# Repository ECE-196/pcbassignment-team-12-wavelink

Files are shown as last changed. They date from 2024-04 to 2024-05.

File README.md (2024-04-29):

Review Assignment Due Date (https://classroom.github.com/a/_vaYiJHp)
# PCBAssignment

**Use the KiCAD project in this repository to make your PCB.**

**Remember to update the changelog**

# Submission

> NOTE: This assignment has multiple deadlines!

> NOTE: This assignment has **no auto-checker** (since there are multiple deadlines), double check you have everything!

1. Image of schematic named `schematic.*` placed in root of this repository. _(By Sunday April 28th)_
1. Image of revised schematic named `schematic.*` and image of layout named `layout.*` placed in root of this repository. _(By Tuesday April 30th)_
1. Final PCB updated in KiCAD project. _(By Friday May 3rd)_
1. Gerber file output ZIP archive named `export.zip` in root of this repository. _(By Friday May 3rd)_
1. Updated changelog

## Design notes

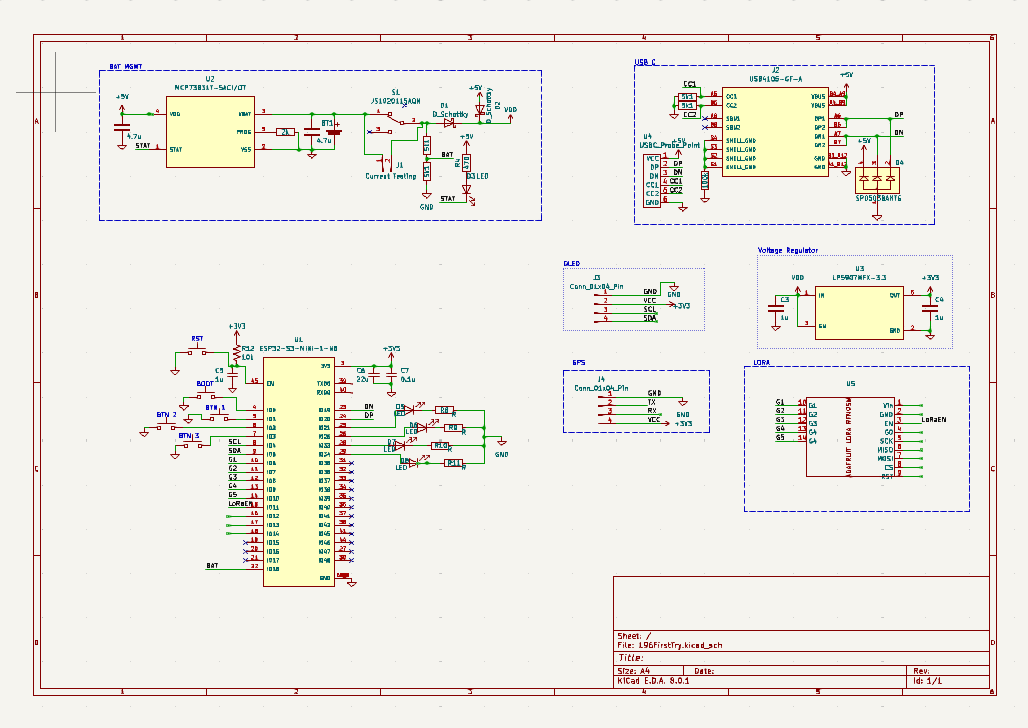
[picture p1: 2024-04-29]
schematic.png

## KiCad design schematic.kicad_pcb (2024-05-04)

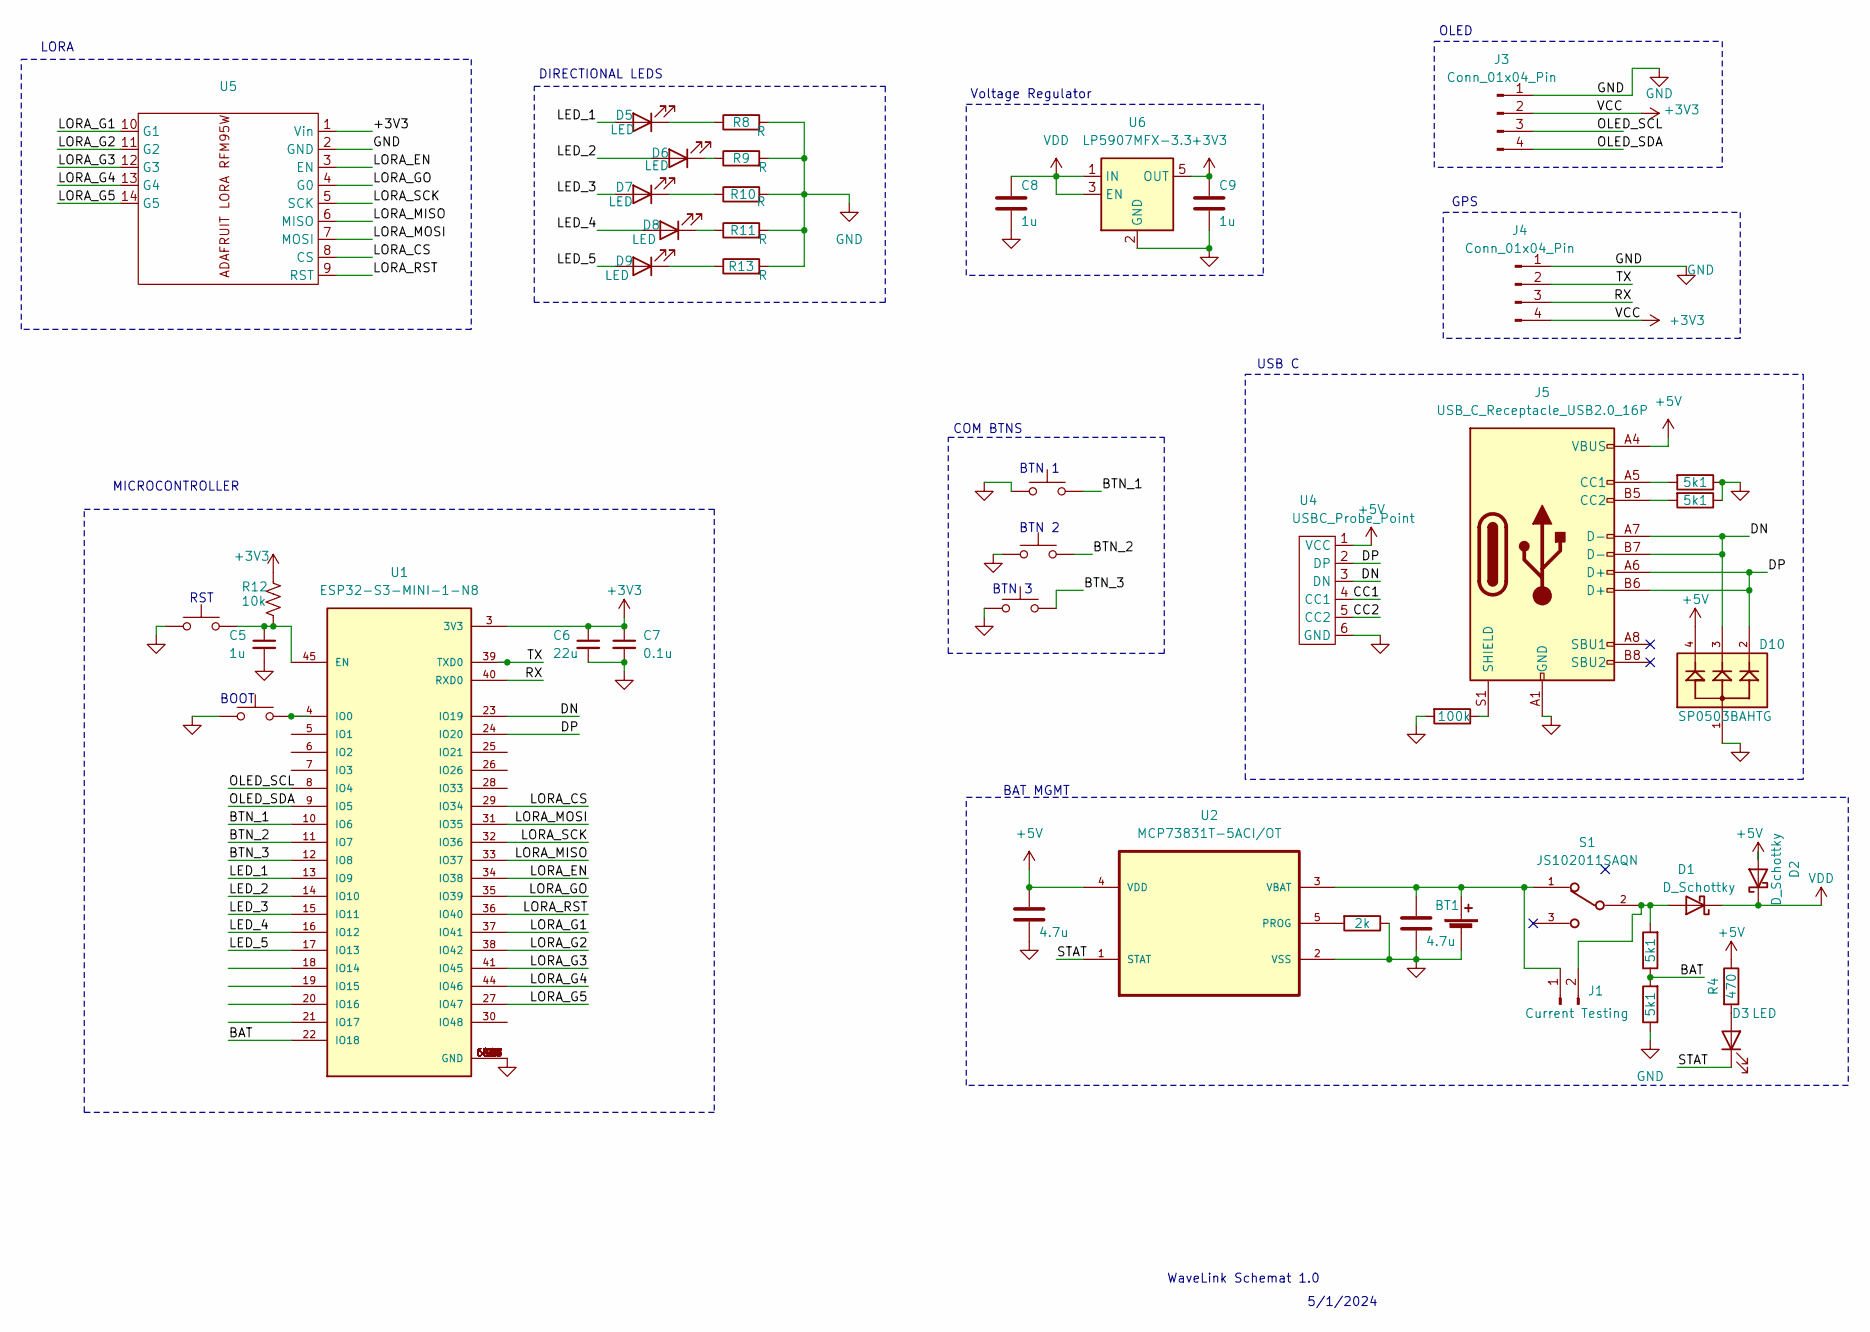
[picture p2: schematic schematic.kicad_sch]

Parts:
BT1: 3.7; PinSocket_1x02_P2.54mm_Vertical
C1, C2: 4.7u; C_0805_2012Metric
C5, C8, C9: 1u; C_0805_2012Metric
C6: 22u; C_0805_2012Metric
C7: 0.1u; C_0805_2012Metric
D1, D2: D_Schottky; D_SOD-523
D3, D5, D6, D7, D8, D9: LED; LED_0805_2012Metric
D10: SP0503BAHTG; SOT-143; PARTREV N/A
J1: Current Testing; PinHeader_1x02_P1.00mm_Vertical
J3, J4: Conn_01x04_Pin; PinHeader_1x04_P2.54mm_Vertical
J5: USB_C_Receptacle_USB2.0_16P; USB_C_Receptacle_GCT_USB4105-xx-A_16P_TopMnt_Horizontal
R1: 2k; R_0805_2012Metric
R2, R3, R5, R6: 5k1; R_0805_2012Metric
R4: 470; R_0805_2012Metric
R7: 100k; R_0805_2012Metric
R8, R9, R10, R11, R13: R; R_0805_2012Metric
R12: 10k; R_0805_2012Metric
S1: JS102011SAQN; SW_SPDT_CK_JS102011SAQN
SW1, SW3, SW4, SW5, SW6: Boot; SW_Push_1P1T_NO_Vertical_Wuerth_434133025816
U1: ESP32-S3-MINI-1-N8; XCVR_ESP32-S3-MINI-1-N8; PARTREV v0.6
U2: MCP73831T-5ACI/OT; SOT-23-5; MPN MCP73831T-5ACI/OT
U4: USBC_Probe_Point; PinHeader_1x06_P1.00mm_Vertical
U5: Lora_Adafruit
U6: LP5907MFX-3.3; SOT-23-5

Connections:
+3V3: C6.1, C7.1, C9.1, J3.2, J4.4, R12.1, U1.3 (3V3), U5.1 (Vin), U6.5 (OUT)
+5V: C1.1, D2.2 (A), D10.4, J5.A4 (VBUS), J5.A9 (VBUS), J5.B4 (VBUS), J5.B9 (VBUS), R4.1, U2.4 (VDD), U4.1 (VCC)
/BAT: R2.1, R3.2, U1.22 (IO18)
/BTN_1: SW4.2, U1.10 (IO6)
/BTN_2: SW5.2, U1.11 (IO7)
/BTN_3: SW6.2, U1.12 (IO8)
/CC1: U4.4 (CC1)
/CC2: U4.5 (CC2)
/DN: D10.3, J5.A7 (D-), J5.B7 (D-), U1.23 (IO19), U4.3 (DN)
/DP: D10.2, J5.A6 (D+), J5.B6 (D+), U1.24 (IO20), U4.2 (DP)
/LED_1: D5.2 (A), U1.13 (IO9)
/LED_2: D6.2 (A), U1.14 (IO10)
/LED_3: D7.2 (A), U1.15 (IO11)
/LED_4: D8.2 (A), U1.16 (IO12)
/LED_5: D9.2 (A), U1.17 (IO13)
/LORA_CS: U1.29 (IO34), U5.8 (CS)
/LORA_EN: U1.34 (IO38), U5.3 (EN)
/LORA_G1: U1.37 (IO41), U5.10 (G1)
/LORA_G2: U1.38 (IO42), U5.11 (G2)
/LORA_G3: U1.41 (IO45), U5.12 (G3)
/LORA_G4: U1.44 (IO46), U5.13 (G4)
/LORA_G5: U1.27 (IO47), U5.14 (G5)
/LORA_GO: U1.35 (IO39), U5.4 (G0)
/LORA_MISO: U1.33 (IO37), U5.6 (MISO)
/LORA_MOSI: U1.31 (IO35), U5.7 (MOSI)
/LORA_RST: U1.36 (IO40), U5.9 (RST)
/LORA_SCK: U1.32 (IO36), U5.5 (SCK)
/OLED_SCL: J3.3, U1.8 (IO4)
/OLED_SDA: J3.4, U1.9 (IO5)
/RX: J4.3, U1.40 (RXD0)
/STAT: D3.1 (K), U2.1 (STAT)
/TX: J4.2, U1.39 (TXD0)
GND: BT1.2 (-), C1.2, C2.2, C5.2, C6.2, C7.2, C8.2, C9.2, D10.1, J3.1, J4.1, J5.A1 (GND), J5.A12 (GND), J5.B1 (GND), J5.B12 (GND), R1.1, R3.1, R5.1, R6.1, R7.2, R8.2, R9.2, R10.2, R11.2, R13.2, SW1.1, SW3.1, SW4.1, SW5.1, SW6.1, U1.1 (GND), U1.2 (GND), U1.42 (GND), U1.43 (GND), U1.46 (GND), U1.47 (GND), U1.48 (GND), U1.49 (GND), U1.50 (GND), U1.51 (GND), U1.52 (GND), U1.53 (GND), U1.54 (GND), U1.55 (GND), U1.56 (GND), U1.57 (GND), U1.58 (GND), U1.59 (GND), U1.60 (GND), U1.61 (GND), U1.61_1 (GND), U1.61_2 (GND), U1.61_3 (GND), U1.61_4 (GND), U1.61_5 (GND), U1.61_6 (GND), U1.61_7 (GND), U1.61_8 (GND), U1.62 (GND), U1.63 (GND), U1.64 (GND), U1.65 (GND), U2.2 (VSS), U4.6 (GND), U5.2 (GND), U6.2 (GND)
unnamed: BT1.1 (+), C2.1, J1.1, S1.1, U2.3 (VBAT)
unnamed: D1.2 (A), J1.2, R2.2, S1.2
unnamed: D3.2 (A), R4.2
unnamed: D5.1 (K), R8.1
unnamed: D6.1 (K), R9.1
unnamed: D7.1 (K), R10.1
unnamed: D8.1 (K), R11.1
unnamed: D9.1 (K), R13.1
unnamed: J5.A5 (CC1), R6.2
unnamed: J5.B5 (CC2), R5.2
unnamed: J5.S1 (SHIELD), R7.1
unnamed: C5.1, R12.2, SW1.2, U1.45 (EN)
unnamed: SW3.2, U1.4 (IO0)
unnamed: R1.2, U2.5 (PROG)
VDD: C8.1, D1.1 (K), D2.1 (K), U6.1 (IN), U6.3 (EN)

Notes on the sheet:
GPS
OLED
RST
COM BTNS
USB C
BTN 2
BOOT
WaveLink Schemat 1.0
BAT MGMT
5/1/2024
Voltage Regulator
LORA
BTN 3
BTN 1
MICROCONTROLLER
DIRECTIONAL LEDS

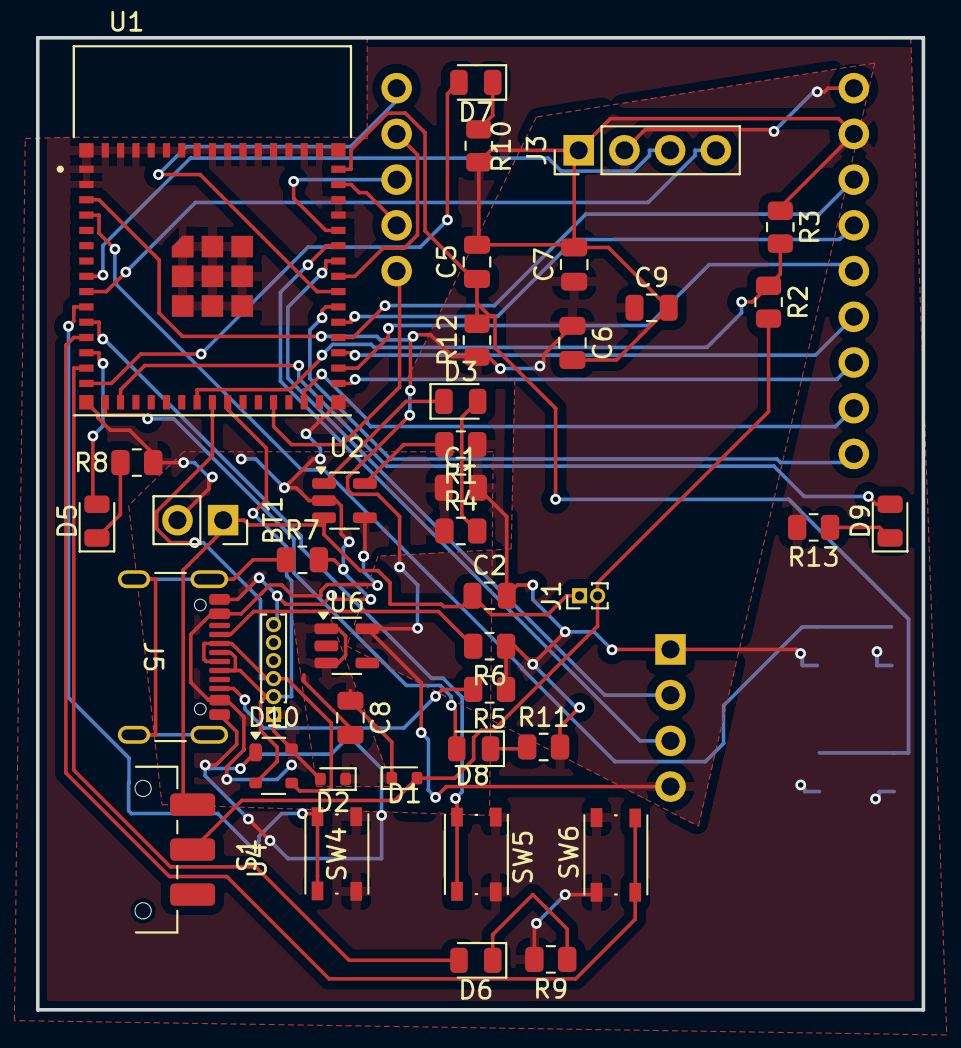
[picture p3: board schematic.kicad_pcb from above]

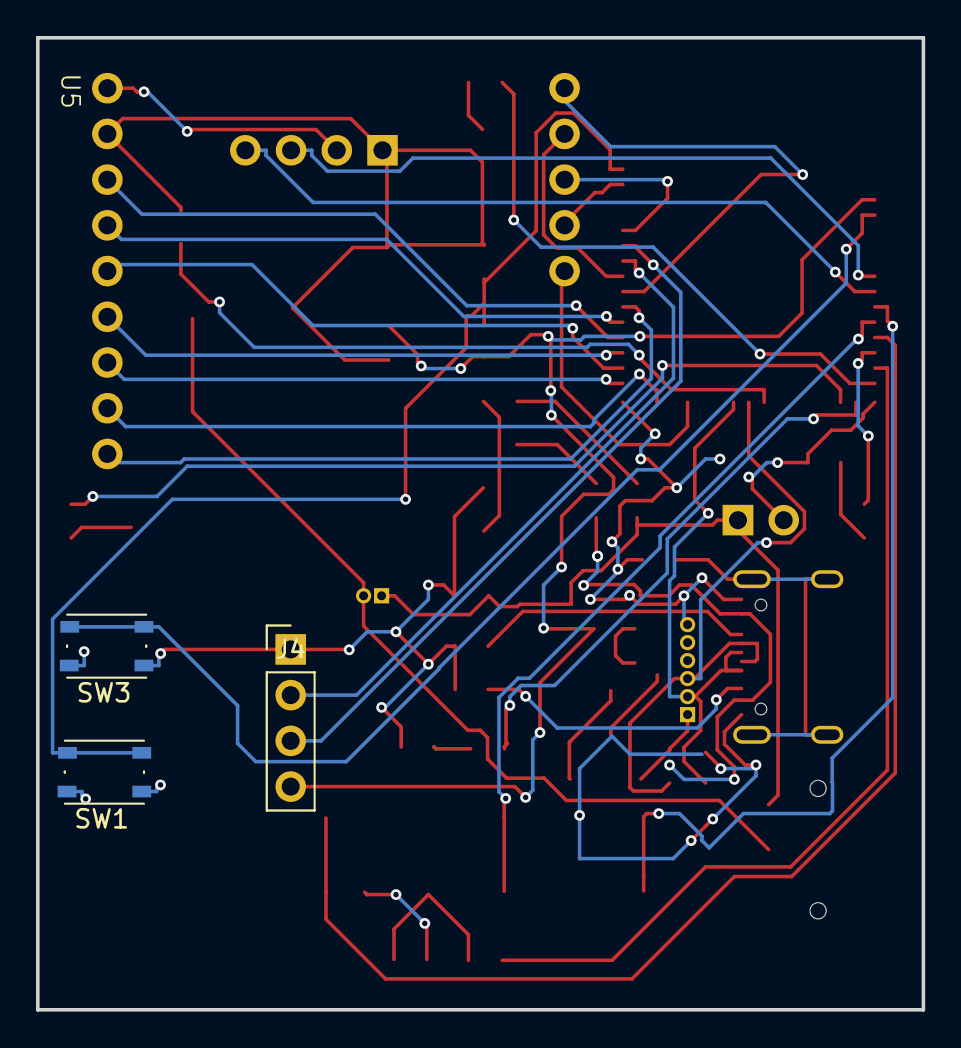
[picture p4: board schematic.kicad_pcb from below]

Board: 2 copper layers, 49.2 x 54.0 mm, 45 parts (4 on the bottom side), 46 nets.

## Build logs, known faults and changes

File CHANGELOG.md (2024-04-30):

# CHANGELOG

## 4/29/24 

### Contributors
Max Gibson, Ronald Ferro-Guerra, Ahn Le

### Added
image of the schematic

### Changed
n/a

### Removed
n/a

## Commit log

2024-04-29 added schematic file
    [schematic.kicad_sch]
2024-04-29 image of the schematic
2024-04-30 updated image of schematic
2024-05-04 uploaded Schematic / PCB / any other needed files
    [schematic.kicad_pcb, schematic.kicad_sch]
2024-05-04 updated schematic image
2024-05-04 generate gerbers...
    [schematic-B_Cu.gbr, schematic-B_Mask.gbr, schematic-B_Paste.gbr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]
